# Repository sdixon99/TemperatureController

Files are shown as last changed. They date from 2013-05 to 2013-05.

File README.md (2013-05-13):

TemperatureController
=====================

Arduino compatible PID based temperature controller.

This controller has been used to control both hot plates and toaster ovens for reflow soldering.  It has also been used for a few other tasks involving temperature control.

The sensor most often used is a modified Harbor Freight IR thermometer which works well for sensing the temperature of a hot plate surface.  The design includes an optional K type thermocouple interface which is more suitable for temperature sensing in a toaster oven (and liquids, etc).

The original design used a MAX6675 thermocouple interface chip.  The code for that design is checked in under tag v1_2.  However, this chip is now end-of-life and has been replaced by the MAX31855.  The latest software and hardware files support the MAX31855.  The MAX31855 is a 3.3V chip so the V1.5 design incorporates 5V to 3.3V level shifting using the pull-ups and diodes design from the Adafruit [breakout board](http://adafruit.com/products/269).

For more information on the earlier design and some additional construction details, see my [blog](http://dorkbotpdx.org/blog/scott_d/installing_the_temperature_controller_code) and the additional information linked there.

The firmware is derived from the [Bare Bones Coffee Controller](http://playground.arduino.cc/Main/BarebonesPIDForEspresso), some standard Arduino libraries and a couple of non-standard libraries (which are included in the libs subdirectory).  

[Pete Skeggs](https://github.com/plskeggs) has modified the firmware to more carefully control the PID timing loop and has gotten good results with a toaster oven.  Note that his code is for the V1.2 board (MAX6675).  It shouldn't be hard to update to the V1.5 design based on the MAX31855.

Non-standard Arduino libraries used (snapshots in libs subdirectory):

RotaryEncoder, written by SunboX: [http://www.arduino.cc/cgi-bin/yabb2/YaBB.pl?num=1205879808]().  The version in libs is updated for Arduino 1.0.

max6675 by Ryan McLaughlin: [http://code.google.com/p/max6675-arduino-library]())

max31855, by Ryan McLuahghlin: [http://ryanjmclaughlin.com/wiki/MAX31855_Arduino_Library]()

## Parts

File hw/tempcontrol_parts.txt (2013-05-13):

Part    Value     Device              Package              Description

3.3V    REG1117   LD1117              SOT223               800mA and 1A Low Dropout (LDO) Digikey 497-1241-1-ND
5V      REG1117   LD1117              SOT223               800mA and 1A Low Dropout (LDO) Digikey 497-1243-1-ND
C5      .1uF      CAP0805             0805                 Capacitor
C6      .1uF      CAP0805             0805                 Capacitor
C7      10uF      CAP_POL3528         EIA3528              Tantalum Capacitor Polarized Digikey 718-1124-1-ND
C8      10uF      CAP_POL3528         EIA3528              Tantalum Capacitor Polarized Digikey 718-1124-1-ND

C1      10uF      CAP_POLPTH2         CPOL-RADIAL-10UF-25V Capacitor Polarized   Digikey P813-ND                       
C2      .1uF      CAP0805             0805                 Capacitor
C3      .1uF      CAP0603             0603
R1      10K       RESISTOR            0805                 Resistor
R2      1K        RESISTOR            0805                 Resistor
R3      10K       TRIM_US-B64Y        B64Y                 POTENTIOMETER Digikey 3352T-103LF-ND
IC1     MEG3288-P MEGA328-P           DIL28-3 MICROCONTROLLER + 28 pin socket  
T1                2N3906-PNP-TO92-EBC TO92-EBC             PNP Transistor
JP1               16MHz Resonator     1X03_LOCK            Digkikey X908-ND

IR                M05LOCK             1X05_LOCK            Header 5 pin
JP7     LCD       PINHD-1X16          1X16                 Female Pin Header
CTRL              M02LOCK             1X02_LOCK            Header 2 pin
ENC               M04LOCK             1X04_LOCK            Header 4 pin                                     
PROG    PROG      M05LOCK             1X05_LOCK            Header 5 pin
PWR_IN            M02LOCK             1X02_LOCK            Header 2 pin
PWR_OUT           M03LOCK             1X03_LOCK            Header 3 pin
RESET             M02LOCK             1X02_LOCK            Header 2 pin
U$1               AVR_SPI_PRG_6NS     2X3-NS               AVR ISP 6 Pin

Encoder (like Bourns 652-PEC11-4215F-S2411R-4215F-S0024) or switches to
change settings

16x2 LCD using HD44780 compatible controller

Harbor Freight IR Thermometer (either Item #93984 or Item #93983)

Optional parts for Thermocouple interface
C4      .1uF      CAP0805             0805                 Capacitor
U$2     MAX31855  MAX31855KASA+       SO08                 Digkikey 700-MAX31855KASA+
D1      1N4148    DIODE               SOD-323F             Mouser 78-1N4148WS-V
D2      1N4148    DIODE               SOD-323F             Mouser 78-1N4148WS-V
R4      10K       RESISTOR            0805                 Resistor
R5      10K       RESISTOR            0805                 Resistor

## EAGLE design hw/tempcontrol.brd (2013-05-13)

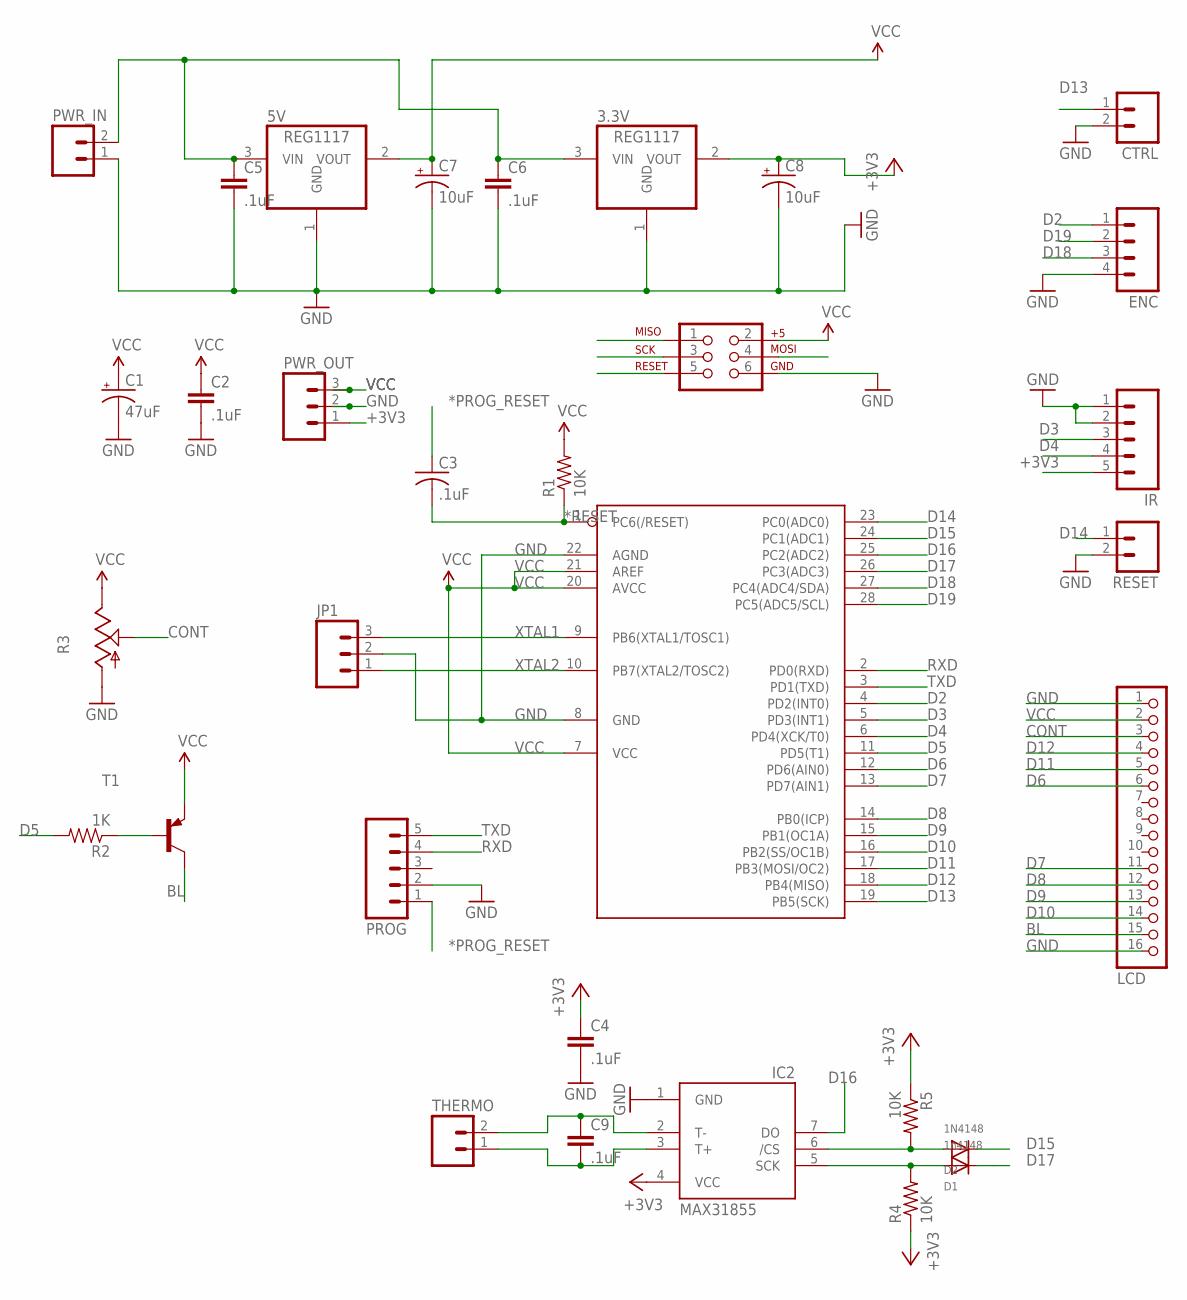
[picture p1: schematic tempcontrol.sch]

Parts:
3.3V, 5V: REG1117; SOT223
C1: 47uF; CPOL-RADIAL-10UF-25V
C2, C4, C5, C6, C9: .1uF; 0805
C3: .1uF; C0805
C7, C8: 10uF; EIA3528
CTRL: M02LOCK; 1X02_LOCK
D1: 1n4148; SOD-323F
D2: 1N4148; SOD-323F
ENC: M04LOCK; 1X04_LOCK
IC1: MEGA8-P; DIL28-3
IC2: MAX31855; SO08
IR: M05LOCK; 1X05_LOCK
JP1: M03LOCK; 1X03_LOCK
JP7: LCD; 1X16
PROG: PROG; 1X05_LOCK
PWR_IN: M02LOCK; 1X02_LOCK
PWR_OUT: M03LOCK; 1X03_LOCK
R1: 10K; 0805
R2: 1K; 0805
R3: TRIM_US-B64Y; B64Y
R4, R5: 10K; R0805
RESET: M02LOCK; 1X02_LOCK
T1: 2N3906-PNP-TO92-EBC; TO92-EBC
THERMO: M02LOCK; 1X02_LOCK
U$1: AVR_SPI_PRG_6NS; 2X3-NS

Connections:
*PROG_RESET: C3.1, PROG.1
*RESET: C3.2, IC1.1 (PC6(/RESET)), R1.1, U$1.5
+3V3: 3.3V.2 (VOUT), C4.1, C8.A (+), IC2.4 (VCC), IR.5, PWR_OUT.1, R4.1, R5.1
BL: JP7.15, T1.C
CONT: JP7.3, R3.S
CS: D2.A, IC2.6 (/CS), R5.2
D2: ENC.1, IC1.4 (PD2(INT0))
D3: IC1.5 (PD3(INT1)), IR.3
D4: IC1.6 (PD4(XCK/T0)), IR.4
D5: IC1.11 (PD5(T1)), R2.2
D6: IC1.12 (PD6(AIN0)), JP7.6
D7: IC1.13 (PD7(AIN1)), JP7.11
D8: IC1.14 (PB0(ICP)), JP7.12
D9: IC1.15 (PB1(OC1A)), JP7.13
D10: IC1.16 (PB2(SS/OC1B)), JP7.14
D11: IC1.17 (PB3(MOSI/OC2)), JP7.5, U$1.4
D12: IC1.18 (PB4(MISO)), JP7.4, U$1.1
D13: CTRL.1, IC1.19 (PB5(SCK)), U$1.3
D14: IC1.23 (PC0(ADC0)), RESET.1
D15: D2.C, IC1.24 (PC1(ADC1))
D16: IC1.25 (PC2(ADC2)), IC2.7 (DO)
D17: D1.C, IC1.26 (PC3(ADC3))
D18: ENC.3, IC1.27 (PC4(ADC4/SDA))
D19: ENC.2, IC1.28 (PC5(ADC5/SCL))
GND: 3.3V.1 (GND), 5V.1 (GND), C1.2 (-), C2.2, C4.2, C5.2, C6.2, C7.C (-), C8.C (-), CTRL.2, ENC.4, IC1.8 (GND), IC1.22 (AGND), IC2.1 (GND), IR.1, IR.2, JP1.2, JP7.1, JP7.16, PROG.2, PWR_IN.1, PWR_OUT.2, R3.A, RESET.2, U$1.6
unnamed: R2.1, T1.B
POS_IN: 3.3V.3 (VIN), 5V.3 (VIN), C5.1, C6.1, PWR_IN.2
RXD: IC1.2 (PD0(RXD)), PROG.4
SCK: D1.A, IC2.5 (SCK), R4.2
T+: C9.2, IC2.3 (T+), THERMO.1
T-: C9.1, IC2.2 (T-), THERMO.2
TXD: IC1.3 (PD1(TXD)), PROG.5
VCC: 5V.2 (VOUT), C1.1 (+), C2.1, C7.A (+), IC1.7 (VCC), IC1.20 (AVCC), IC1.21 (AREF), JP7.2, PWR_OUT.3, R1.2, R3.E, T1.E, U$1.2
XTAL1: IC1.9 (PB6(XTAL1/TOSC1)), JP1.3
XTAL2: IC1.10 (PB7(XTAL2/TOSC2)), JP1.1

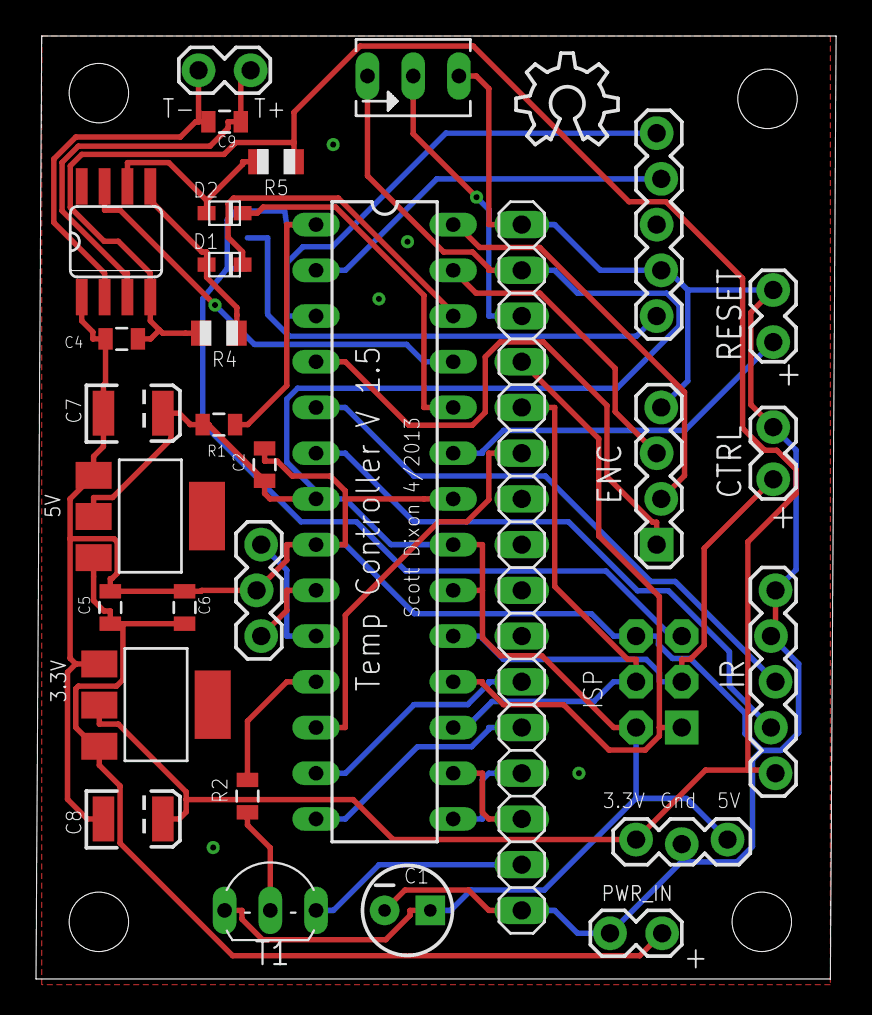
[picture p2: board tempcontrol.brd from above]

Board: 2 copper layers, 44.5 x 52.4 mm, 37 parts (1 on the bottom side), 35 nets.

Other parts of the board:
U$2: OSHW_8X200_NOTEXT
U$3, U$4, U$5, U$6: STAND-OFF

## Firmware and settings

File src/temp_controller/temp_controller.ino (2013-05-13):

// BBCC Main
// Tim Hirzel
// February 2008
//
// Main file for the Bare Bones Coffee Controller PID 
// setup for Arduino.
// This project is set up such that each tab acts as a 
// "module" or "library" that incporporates some more 
// functionality.  Each tab correlates 
// to a particular device (Nunchuck),  protocol (ie. SPI), 
// or Algorithm (ie. PID).

// The general rule for any of these tabs/sections is that 
// if they include a setup* or update* function, those should be added
// into the main setup and main loop functions. Also, in main loop, and in 
// extra code, delays should probably be avoided.
// Instead, use millis() and check for a certain interval to have passed.
//
// All code released under
// Creative Commons Attribution-Noncommercial-Share Alike 3.0 
// Modifications for hot plate SMD reflow by Scott Dixon, March 2010.


// These are addresses into EEPROM memory.  The values to be stores are floats which 
// need 4 bytes each.  Thus 0,4,8,12,...
#define PGAIN_ADR 0
#define IGAIN_ADR 4
#define DGAIN_ADR 8
#define RESET_BUTTON 14

#define ESPRESSO_TEMP_ADDRESS 12
//#define STEAM_TEMP_ADDRESS 12  // steam temp currently not used with bare bones setup

#define PID_UPDATE_INTERVAL 200 // milliseconds


float targetTemp;  //current temperature goal
float heatPower; // 0 - 1000  milliseconds on per second
float thermo_temp;

unsigned long lastPIDTime;  // most recent PID update time in ms 

void setup()
{
  pinMode(RESET_BUTTON, INPUT);
  digitalWrite(RESET_BUTTON, HIGH);
  setupPID(PGAIN_ADR, IGAIN_ADR, DGAIN_ADR ); // Send addresses to the PID module 
  targetTemp = readFloat(ESPRESSO_TEMP_ADDRESS); // from EEPROM. load the saved value
  setupLCD(targetTemp, true);
  lastPIDTime = millis();
  // module setup calls
  setupHeater();
  setupSerialInterface();
  setupTempSensor();
  thermo_temp = updateMax();
}

void setTargetTemp(float t) {
  targetTemp = t;
  writeFloat(t, ESPRESSO_TEMP_ADDRESS);
}

float getTargetTemp() {
  return targetTemp;
}


void loop()
{  
  float new_temp;
  if (digitalRead(RESET_BUTTON) == LOW) {
      targetTemp = readFloat(ESPRESSO_TEMP_ADDRESS); // from EEPROM. load the saved value
      setupLCD(targetTemp, false);
  }
  // this call interprets characters from the serial port
  // its a very basic control to allow adjustment of gain values, and set temp
  updateSerialInterface(); 
  updateTempSensor();

  // every second, udpate the current heat control, and print out current status

  // This checks for rollover with millis()
  if (millis() < lastPIDTime) {
    lastPIDTime = 0;
  }

  if ((millis() - lastPIDTime) > PID_UPDATE_INTERVAL) {
  new_temp = updateLCD(targetTemp, getLastTemp(), thermo_temp);
  if (new_temp > 0) {
    targetTemp = new_temp;
  }
    lastPIDTime +=  PID_UPDATE_INTERVAL;
    heatPower = updatePID(targetTemp, getFreshTemp());
    setHeatPowerPercentage(heatPower);
    thermo_temp = updateMax();
  }  
  updateHeater();




}

// END BBCC Main

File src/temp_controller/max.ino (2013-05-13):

#include <MAX31855.h>

int CS = 15;              // CS pin on MAX31855
int SO = 16;              // SO pin of MAX31855
int SCLK = 17;             // SCK pin of MAX31855
float temperature = 0.0;  // Temperature output variable
MAX31855 temp0(SCLK, CS, SO);

float updateMax() {
  int i, cd;
  double tmp = 0.0;
  
  for (i=0;i<5;i++) {
    cd = temp0.readFaultCode();
    if (cd != 0) {
      return -9990.0 - cd;
    }
     tmp += temp0.readCelsius();        // Read the temp 5 times and return the average value
  }
  return tmp/5.0;
}
